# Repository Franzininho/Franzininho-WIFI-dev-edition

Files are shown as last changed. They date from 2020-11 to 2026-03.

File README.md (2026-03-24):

# Franzininho WiFi Developer Edition

The **Franzininho WiFi Developer Edition** is a development board designed to evaluate **ESP32-S2 modules** (WROOM and WROVER) and to support the development of the next generation of Franzininho boards.

The Franzininho project was created to help people develop skills in electronics and programming through *DIY* (Do-It-Yourself) activities, aligned with the *maker culture* in Brazil.

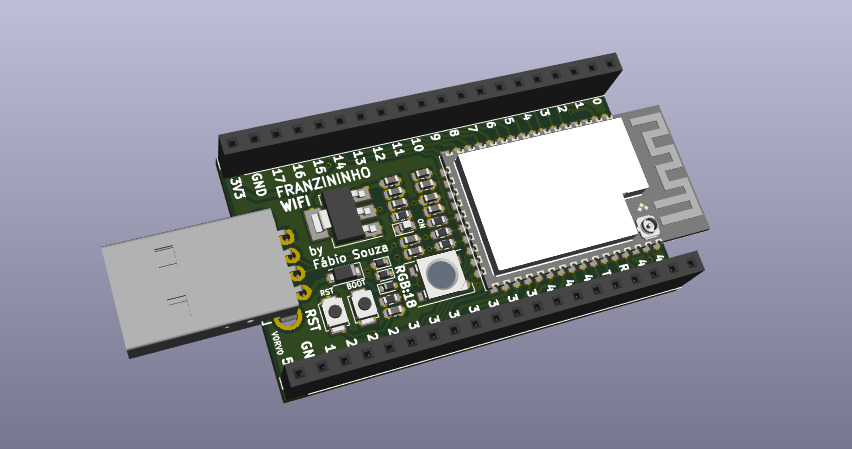
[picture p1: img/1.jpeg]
front


As there are still few ESP32-S2-based boards available in the Brazilian market, the Franzininho WiFi was developed to serve as a development platform for this SoC, as well as to help evaluate and validate applications.

---

## Features

### ESP32-S2 Module (WROOM or WROVER)
- Xtensa® LX7 32-bit single-core microprocessor, up to 240 MHz  
- 128 KB ROM  
- 320 KB SRAM  
- 16 KB RTC SRAM  
- 2 MB (8 Mbit) PSRAM (WROVER module only)  
- Wi-Fi 802.11 b/g/n  

### Interfaces
- GPIO, SPI, LCD, UART, I2C, I2S  
- Camera interface  
- IR, pulse counter, LED PWM  
- TWAI (compatible with ISO 11898-1)  
- USB 1.1 OTG  
- ADC, DAC  
- Touch sensor  
- Temperature sensor  

### Hardware
- USB Type-A male connector  
- RGB LED (WS2812) (GPIO 18)  
- 40 pins broken out to 2x20 headers (2.54 mm pitch, 36 GPIOs) — breadboard-friendly  
- Reset and DFU (BOOT0) buttons to enter the ROM bootloader (USB serial, no external adapter required)  
- Serial debug pins (TX and RX) for hardware debug console  
- JTAG pads for advanced debugging access  
- 3.3 V power indicator LED  
- 3.3 V voltage regulator  

### Power Supply
- Micro USB port (default power source)  
- 5 V and GND header pins  
- 3V3 and GND header pins  

### Dimensions
- 72 mm x 30 mm  

### Compatibility
- Compatible with [ESP-IDF](https://docs.espressif.com/projects/esp-idf/en/latest/esp32s2/get-started/index.html)  
- Compatible with [CircuitPython](https://circuitpython.org/)  

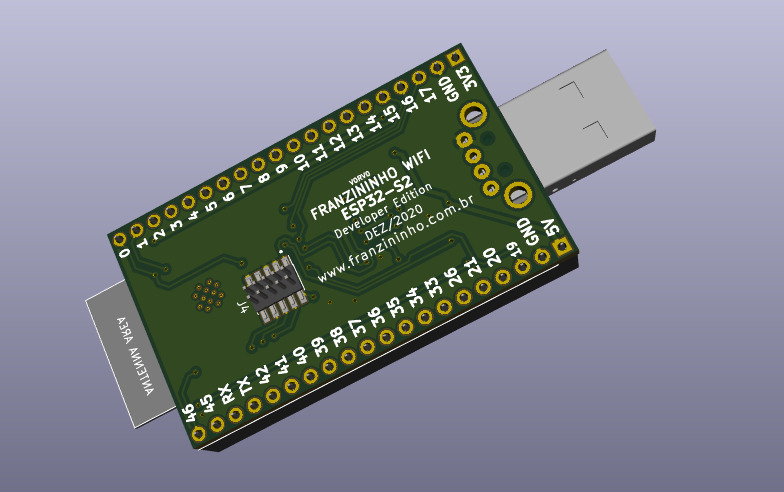
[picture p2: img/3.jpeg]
back


---

## License

This project is open-source hardware and is released under the **CERN Open Hardware License**.

The Franzininho WiFi board is certified by OSHWA:  
[UID BR000006](https://certification.oshwa.org/br000006.html)

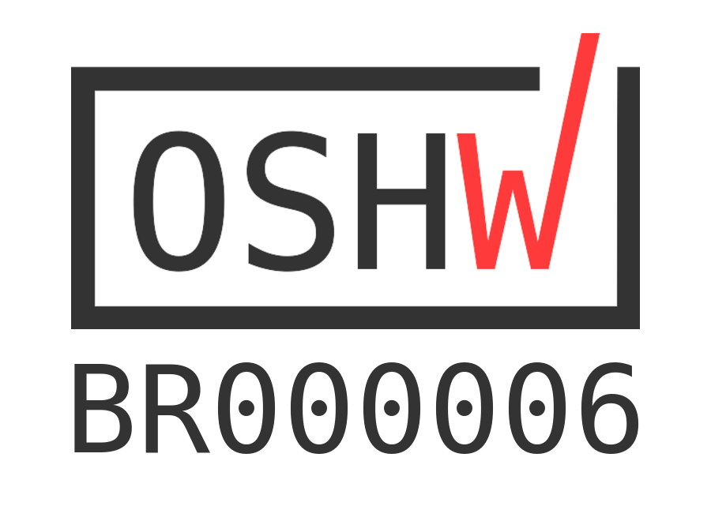
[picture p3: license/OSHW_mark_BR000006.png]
oshwa


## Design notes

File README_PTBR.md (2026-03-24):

# Franzininho WiFi

A **Franzininho WiFi** é uma placa de desenvolvimento projetada para avaliar os módulos **ESP32-S2** (WROOM e WROVER) e apoiar a criação da nova geração de placas Franzininho.

O projeto Franzininho foi criado com o objetivo de desenvolver habilidades em eletrônica e programação, por meio de atividades no formato *DIY* (faça você mesmo) e alinhadas à cultura *maker*, no Brasil.

front

Como ainda há poucas placas com ESP32-S2 disponíveis no mercado brasileiro, a Franzininho WiFi foi desenvolvida para servir como uma plataforma de desenvolvimento baseada nesse SoC, além de auxiliar na avaliação e validação de aplicações.

---

## Características

### Módulo ESP32-S2 (WROOM ou WROVER)
- Microprocessador Xtensa® LX7, 32 bits, single-core, até 240 MHz  
- 128 KB de ROM  
- 320 KB de SRAM  
- 16 KB de SRAM em RTC  
- 2 MB (8 Mbit) de PSRAM (apenas no módulo WROVER)  
- Wi-Fi 802.11 b/g/n  

### Interfaces
- GPIO, SPI, LCD, UART, I2C, I2S  
- Interface para câmera  
- IR, contador de pulsos, PWM para LED  
- TWAI (compatível com ISO 11898-1)  
- USB 1.1 OTG  
- ADC, DAC  
- Sensor de toque  
- Sensor de temperatura  

### Hardware
- Conector USB Tipo-A macho  
- LED RGB (WS2812) (GPIO 18)  
- 40 pinos expostos em headers 2x20 (passo 2,54 mm, 36 GPIOs) — compatível com protoboard  
- Botões de Reset e DFU (BOOT0) para acesso ao bootloader ROM (via USB, sem necessidade de cabo adicional)  
- Pinos de depuração serial (TX e RX)  
- Pads JTAG para depuração avançada  
- LED indicador de alimentação 3,3 V  
- Regulador de 3,3 V  

### Alimentação
- Porta Micro USB (padrão)  
- Pinos 5 V e GND  
- Pinos 3V3 e GND  

### Dimensões
- 72 mm x 30 mm  

### Compatibilidade
- Compatível com [ESP-IDF](https://docs.espressif.com/projects/esp-idf/en/latest/esp32s2/get-started/index.html)  
- Compatível com [CircuitPython](https://circuitpython.org/)  

back

---

## Licença

Este projeto é um hardware de código aberto e está disponível sob a licença **CERN Open Hardware License**.

A placa Franzininho WiFi é certificada pela OSHWA:  
[UID BR000006](https://certification.oshwa.org/br000006.html)

oshwa

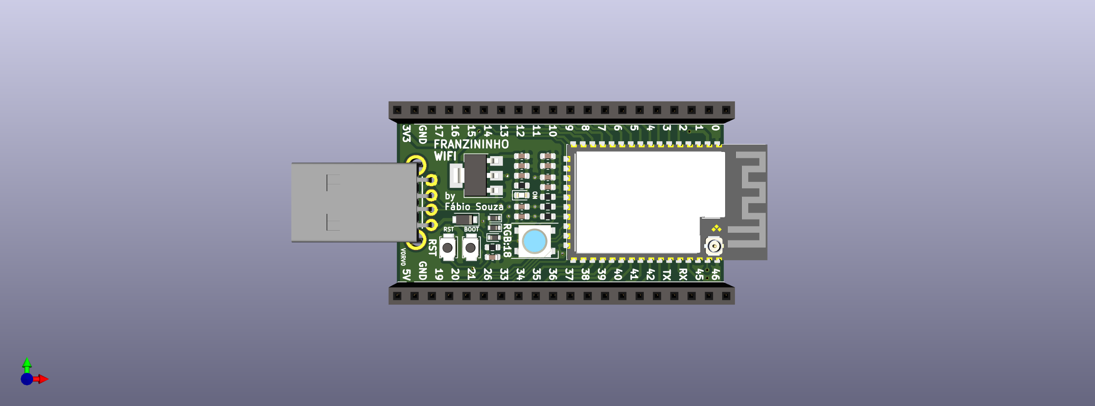
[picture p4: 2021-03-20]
img/Franzininho WIFI.png

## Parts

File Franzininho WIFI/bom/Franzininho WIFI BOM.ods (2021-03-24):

Reference | Value | Footprint | Datasheet | LCSC | PN | Montado | Tem estoque
C4 | 20pF | Capacitor_SMD:C_0603_1608Metric | https://datasheet.lcsc.com/szlcsc/Samsung-Electro-Mechanics-CL10C200JB8NNNC_C1648.pdf | C1648 | CL10C200JB8NNNC | Sim | Não
J2 | Conn_01x20_Male | Connector_PinSocket_2.54mm:PinSocket_1x20_P2.54mm_Vertical | ~ |  |  | Sim | Não
R3 | 0 | Resistor_SMD:R_0603_1608Metric | ~ | C21189 | 0603WAF0000T5E | Sim | Não
R4 | 0 | Resistor_SMD:R_0603_1608Metric | ~ | C21189 | 0603WAF0000T5E | Sim | Não
C3 | 10uF | Capacitor_SMD:C_0603_1608Metric | Samsung-Electro-Mechanics-CL10A106KP8NNNC_C19702.pdf | C19702 | CL10A106KP8NNNC | Sim | Não
C1 | 10uF | Capacitor_SMD:C_0603_1608Metric | Samsung-Electro-Mechanics-CL10A106KP8NNNC_C19702.pdf | C19702 | CL10A106KP8NNNC | Sim | Não
C7 | 10uF | Capacitor_SMD:C_0603_1608Metric | Samsung-Electro-Mechanics-CL10A106KP8NNNC_C19702.pdf | C19702 | CL10A106KP8NNNC | Sim | Não
C9 | 10uF | Capacitor_SMD:C_0603_1608Metric | Samsung-Electro-Mechanics-CL10A106KP8NNNC_C19702.pdf | C19702 | CL10A106KP8NNNC | Sim | Não
D3 | 1N5819W | Diode_SMD:D_SOD-123F | Shandong-Jingdao-Microelectronics-1N5819W_C169540.pdf | C169540 | 1N5819W | Sim | Não
C6 | 1uF | Capacitor_SMD:C_0603_1608Metric | https://datasheet.lcsc.com/szlcsc/Samsung-Electro-Mechanics-CL10A105KB8NNNC_C15849.pdf | C15849 | CL10A105KB8NNNC | Sim | Não
C5 | 20pF | Capacitor_SMD:C_0603_1608Metric | https://datasheet.lcsc.com/szlcsc/Samsung-Electro-Mechanics-CL10C200JB8NNNC_C1648.pdf | C1648 | CL10C200JB8NNNC | Sim | Não
U2 | BL1117-33CX | Package_TO_SOT_SMD:SOT-223-3_TabPin2 | https://datasheet.lcsc.com/szlcsc/Shanghai-Belling-BL1117-33CX_C5400.pdf | C5400 | BL1117-33CX | Sim | Não
J3 | Conn_01x20_Male | Connector_PinSocket_2.54mm:PinSocket_1x20_P2.54mm_Vertical | ~ |  |  | Sim | Não
D1 | LESD5D5.0CT1G | Diode_SMD:D_SOD-523 | https://datasheet.lcsc.com/szlcsc/Leshan-Radio-LESD5Z5-0T1G_C136171.pdf | C136171 | LESD5Z5.0T1G | Sim | Não
D2 | LESD5D5.0CT1G | Diode_SMD:D_SOD-523 | https://datasheet.lcsc.com/szlcsc/Leshan-Radio-LESD5Z5-0T1G_C136171.pdf | C136171 | LESD5Z5.0T1G | Sim | Não
D4 | LESD5D5.0CT1G | Diode_SMD:D_SOD-523 | https://datasheet.lcsc.com/szlcsc/Leshan-Radio-LESD5Z5-0T1G_C136171.pdf | C136171 | LESD5Z5.0T1G | Sim | Não
J1 | USB-A-H | LIBS:USB-A-H |  | C112454 | USB-05 | Sim | Não
D6 | WS2812B | LED_SMD:LED_WS2812B_PLCC4_5.0x5.0mm_P3.2mm | https://datasheet.lcsc.com/szlcsc/Worldsemi-WS2812B-B_C114586.pdf | C114586 | WS2812B-B | Sim | Não
C2 | 100nF | Capacitor_SMD:C_0603_1608Metric | https://datasheet.lcsc.com/szlcsc/YAGEO-CC0603KRX7R9BB104_C14663.pdf | C14663 | CC0603KRX7R9BB104 | Sim | Sim
C8 | 100nF | Capacitor_SMD:C_0603_1608Metric | https://datasheet.lcsc.com/szlcsc/YAGEO-CC0603KRX7R9BB104_C14663.pdf | C14663 | CC0603KRX7R9BB104 | Sim | Sim
C10 | 100nF | Capacitor_SMD:C_0603_1608Metric | https://datasheet.lcsc.com/szlcsc/YAGEO-CC0603KRX7R9BB104_C14663.pdf | C14663 | CC0603KRX7R9BB104 | Sim | Sim
R1 | 10k | Resistor_SMD:R_0603_1608Metric | ~ | C25804 | 0603WAF1002T5E | Sim | Sim
R2 | 10k | Resistor_SMD:R_0603_1608Metric | ~ | C25804 | 0603WAF1002T5E | Sim | Sim
R5 | 10k | Resistor_SMD:R_0603_1608Metric | ~ | C25804 | 0603WAF1002T5E | Sim | Sim
U1 | esp32-s2-wroom | esp32-s2:esp32-s2-wrooom | https://www.espressif.com/sites/default/files/documentation/esp32-s2-wroom_esp32-s2-wroom-i_datasheet_en.pdf | C967025 | ESP32-S2-WROOM(4M) | Sim | Sim
D5 | LED | LED_SMD:LED_0603_1608Metric | https://datasheet.lcsc.com/szlcsc/Hubei-KENTO-Elec-XL-0603QYGC_C2289.pdf | C2289 | XL-0603QYGC | Sim | Sim
SW1 | SW_Push | Button_Switch_SMD:SW_SPST_B3U-1000P | https://datasheet.lcsc.com/szlcsc/1810010153_Omron-Electronics-B3U-1000P_C231329.pdf | C231329 | B3U-1000P | Sim | Sim
SW2 | SW_Push | Button_Switch_SMD:SW_SPST_B3U-1000P | https://datasheet.lcsc.com/szlcsc/1810010153_Omron-Electronics-B3U-1000P_C231329.pdf | C231329 | B3U-1000P | Sim | Sim

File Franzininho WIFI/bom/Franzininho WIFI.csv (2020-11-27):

Id | Designator | Package | Quantity | Designation | Supplier and ref
1 | G*** | bandeiraBrasil | 1 | LOGO
2 | G*** | logo-franzininho12_7 | 1 | LOGO
3 | J3,J2 | PinSocket_1x20_P2.54mm_Vertical | 2 | Conn_01x20_Male
4 | C2,C8,C10 | C_0603_1608Metric | 3 | 100nF
5 | R1,R2,R5 | R_0603_1608Metric | 3 | 10k
6 | U1 | esp32-s2-wrooom | 1 | esp32-s2-wroom
7 | C1,C3,C7,C9 | C_0603_1608Metric | 4 | 10uF
8 | C4,C5 | C_0603_1608Metric | 2 | 20pF
9 | C6 | C_0603_1608Metric | 1 | 1uF
10 | D3 | D_SOD-123F | 1 | 1N5819W
11 | J1 | USB-A-H | 1 | USB-A-H
12 | R3,R4 | R_0603_1608Metric | 2 | 0
13 | D1,D2,D4 | D_SOD-523 | 3 | LESD5D5.0CT1G
14 | U2 | SOT-223-3_TabPin2 | 1 | BL1117-33CX
15 | D5 | LED_0603_1608Metric | 1 | LED
16 | SW1,SW2 | SW_SPST_B3U-1000P | 2 | SW_Push
17 | D6 | LED_WS2812B_PLCC4_5.0x5.0mm_P3.2mm | 1 | WS2812B
18 | J4 | PinHeader_2x05_P1.27mm_Vertical_SMD | 1 | Conn_ARM_JTAG_SWD_10

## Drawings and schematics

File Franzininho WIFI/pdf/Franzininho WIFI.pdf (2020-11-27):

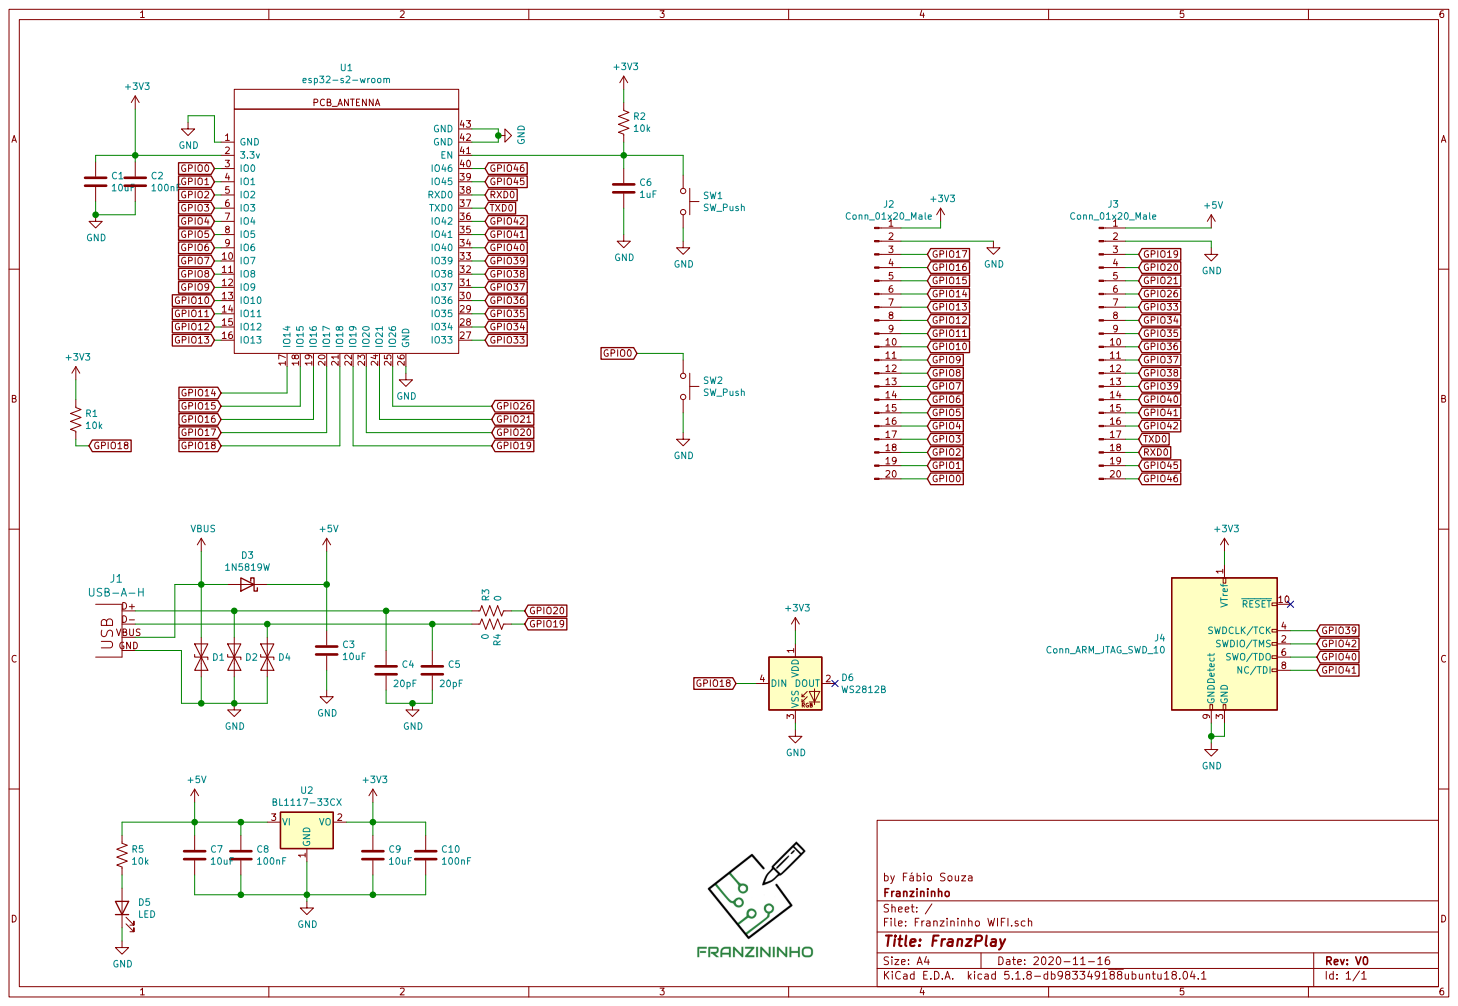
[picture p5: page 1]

3 SWDCLK/TCK 4 SWO/TDO 6 NC/TDI 8 GNDDetect 9

File: Franzininho WIFI.sch Sheet: / Franzininho

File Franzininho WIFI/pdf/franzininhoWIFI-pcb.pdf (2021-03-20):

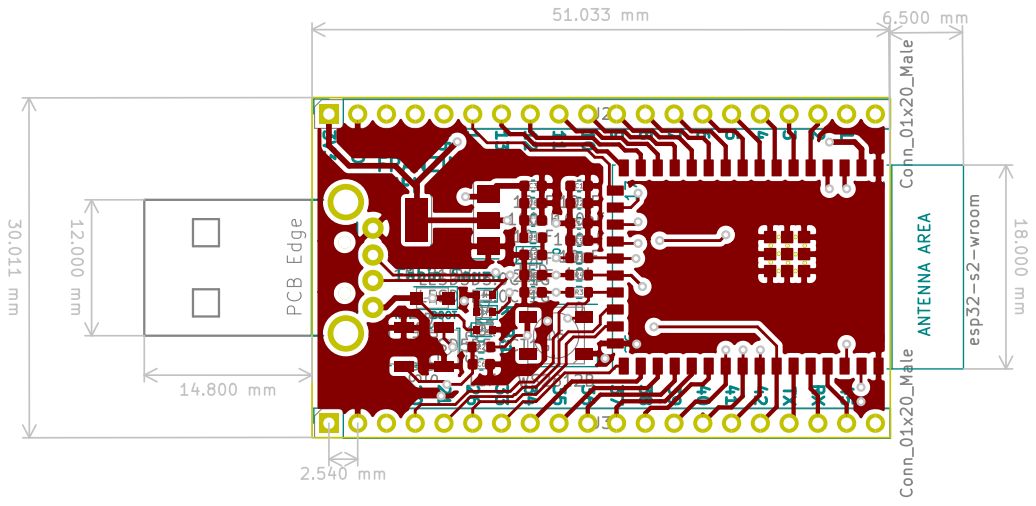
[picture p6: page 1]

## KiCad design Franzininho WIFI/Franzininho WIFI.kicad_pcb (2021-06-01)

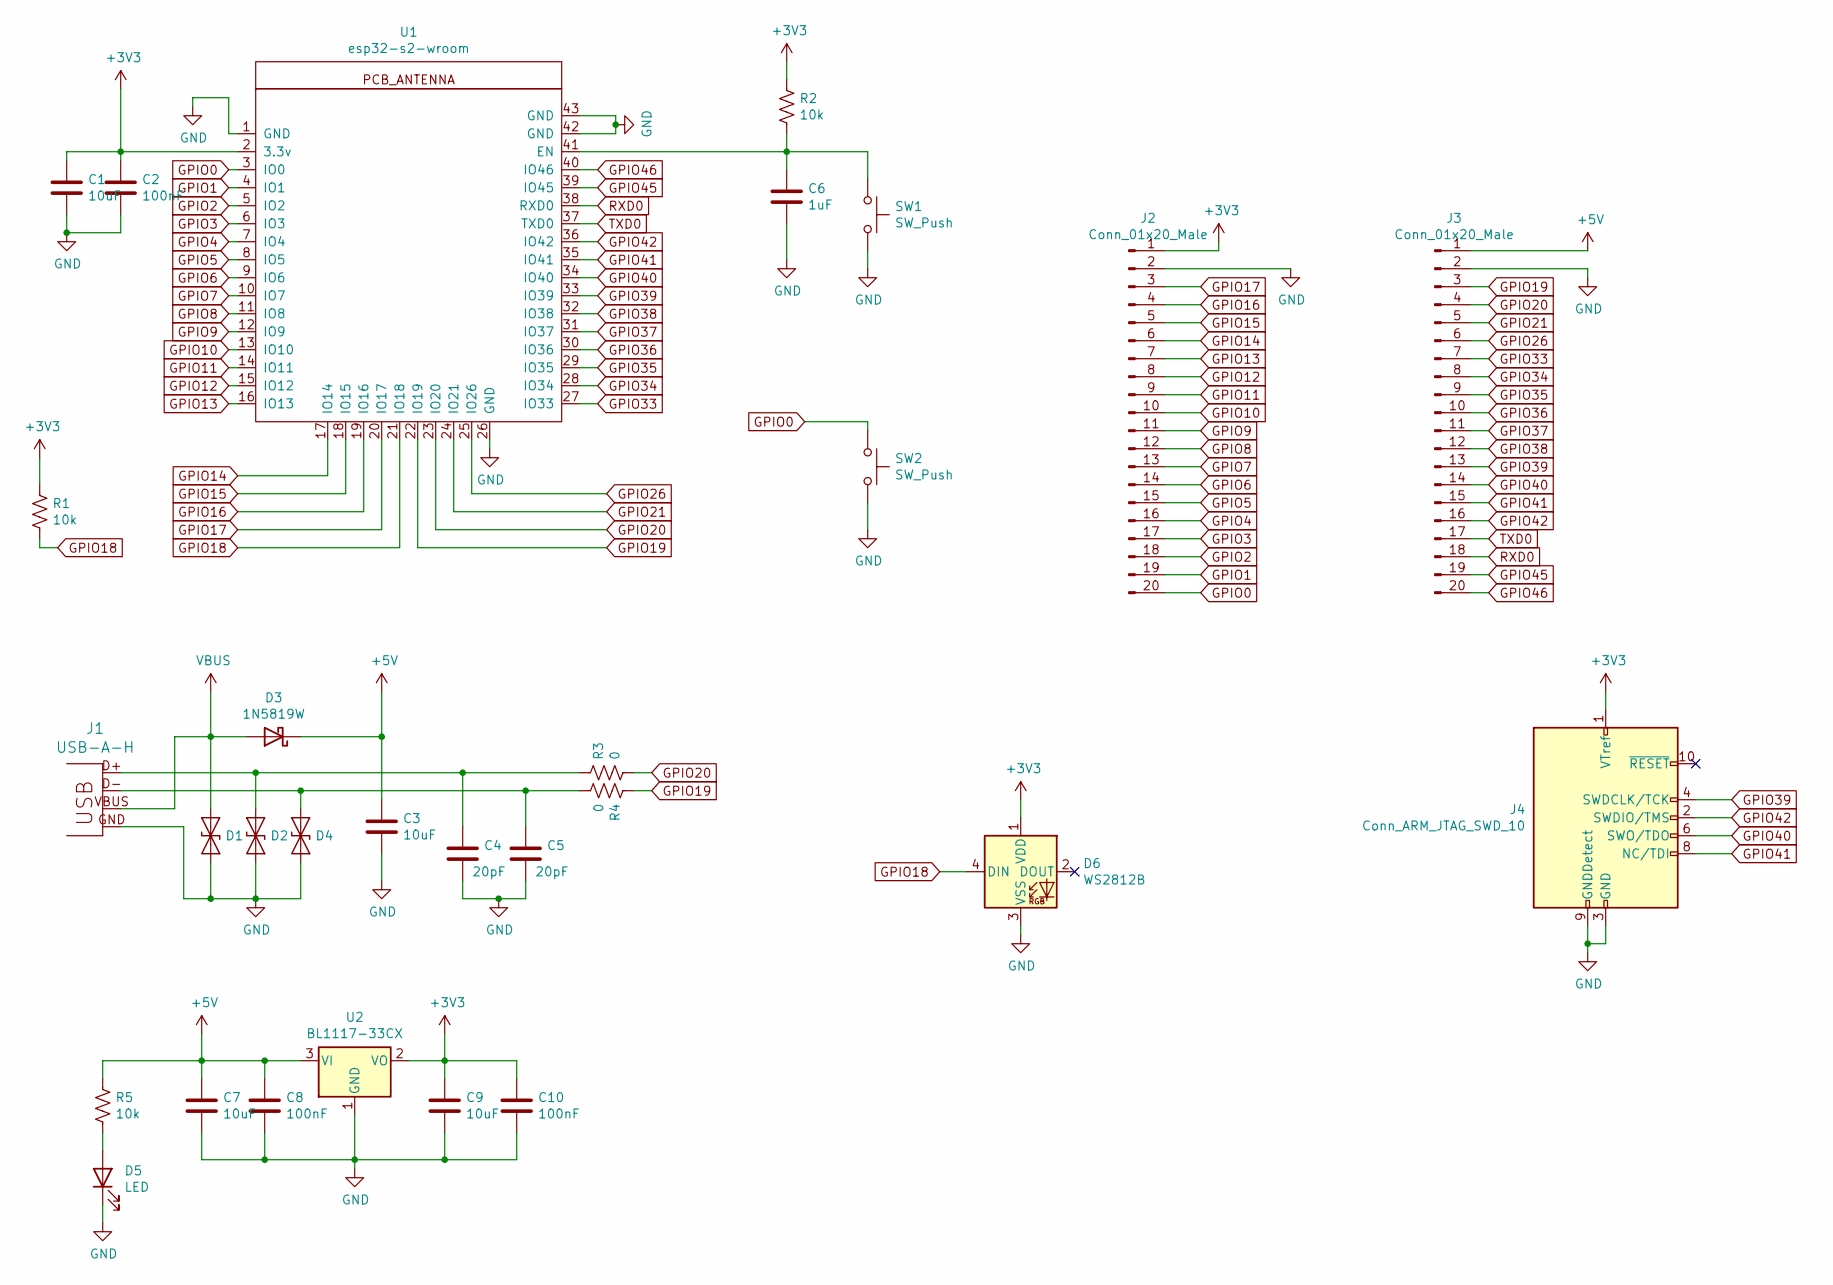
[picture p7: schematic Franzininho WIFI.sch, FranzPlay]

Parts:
C1, C3, C7, C9: 10uF; C_0603_1608Metric; LCSC C19702
C2, C8, C10: 100nF; C_0603_1608Metric; LCSC C14663
C4, C5: 20pF; C_0603_1608Metric; LCSC C1648
C6: 1uF; C_0603_1608Metric; LCSC C15849
D1, D2, D4: LESD5D5.0CT1G; D_SOD-523; LCSC C136171
D3: 1N5819W; D_SOD-123F; LCSC C169540
D5: LED; LED_0603_1608Metric; LCSC C2289
D6: WS2812B; LED_WS2812B_PLCC4_5.0x5.0mm_P3.2mm; LCSC C114586
J1: USB-A-H
J2, J3: Conn_01x20_Male; PinSocket_1x20_P2.54mm_Vertical
J4: Conn_ARM_JTAG_SWD_10; PinHeader_2x05_P1.27mm_Vertical_SMD
R1, R2, R5: 10k; R_0603_1608Metric; LCSC C25804
R3, R4: 0; R_0603_1608Metric; LCSC C21189
SW1, SW2: SW_Push; SW_SPST_B3U-1000P
U1: esp32-s2-wroom; esp32-s2-wrooom
U2: BL1117-33CX; SOT-223-3_TabPin2; LCSC C5400

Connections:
+3V3: C1.1, C2.1, C9.1, C10.1, D6.1 (VDD), J2.1, J4.1 (VTref), R1.1, R2.1, U1.2 (3.3v), U2.2 (VO)
+5V: C3.1, C7.1, C8.1, D3.1 (K), J3.1, R5.1, U2.3 (VI)
GND: C1.2, C2.2, C3.2, C4.2, C5.2, C6.2, C7.2, C8.2, C9.2, C10.2, D1.2 (A2), D2.2 (A2), D4.2 (A2), D5.1 (K), D6.3 (VSS), J1.GND, J2.2, J3.2, J4.3 (GND), J4.5 (GND), J4.9 (GNDDetect), SW1.2, SW2.2, U1.1 (GND), U1.26 (GND), U1.42 (GND), U1.43 (GND), U2.1 (GND)
GPIO0: J2.20, SW2.1, U1.3 (IO0)
GPIO1: J2.19, U1.4 (IO1)
GPIO2: J2.18, U1.5 (IO2)
GPIO3: J2.17, U1.6 (IO3)
GPIO4: J2.16, U1.7 (IO4)
GPIO5: J2.15, U1.8 (IO5)
GPIO6: J2.14, U1.9 (IO6)
GPIO7: J2.13, U1.10 (IO7)
GPIO8: J2.12, U1.11 (IO8)
GPIO9: J2.11, U1.12 (IO9)
GPIO10: J2.10, U1.13 (IO10)
GPIO11: J2.9, U1.14 (IO11)
GPIO12: J2.8, U1.15 (IO12)
GPIO13: J2.7, U1.16 (IO13)
GPIO14: J2.6, U1.17 (IO14)
GPIO15: J2.5, U1.18 (IO15)
GPIO16: J2.4, U1.19 (IO16)
GPIO17: J2.3, U1.20 (IO17)
GPIO18: D6.4 (DIN), R1.2, U1.21 (IO18)
GPIO19: J3.3, R4.1, U1.22 (IO19)
GPIO20: J3.4, R3.2, U1.23 (IO20)
GPIO21: J3.5, U1.24 (IO21)
GPIO26: J3.6, U1.25 (IO26)
GPIO33: J3.7, U1.27 (IO33)
GPIO34: J3.8, U1.28 (IO34)
GPIO35: J3.9, U1.29 (IO35)
GPIO36: J3.10, U1.30 (IO36)
GPIO37: J3.11, U1.31 (IO37)
GPIO38: J3.12, U1.32 (IO38)
GPIO39: J3.13, J4.4 (SWDCLK/TCK), U1.33 (IO39)
GPIO40: J3.14, J4.6 (SWO/TDO), U1.34 (IO40)
GPIO41: J3.15, J4.8 (NC/TDI), U1.35 (IO41)
GPIO42: J3.16, J4.2 (SWDIO/TMS), U1.36 (IO42)
GPIO45: J3.19, U1.39 (IO45)
GPIO46: J3.20, U1.40 (IO46)
unnamed: C4.1, D2.1 (A1), J1.D+, R3.1
unnamed: C5.1, D4.1 (A1), J1.D-, R4.2
unnamed: C6.1, R2.2, SW1.1, U1.41 (EN)
unnamed: D5.2 (A), R5.2
RXD0: J3.18, U1.38 (RXD0)
TXD0: J3.17, U1.37 (TXD0)
VBUS: D1.1 (A1), D3.2 (A), J1.VBUS

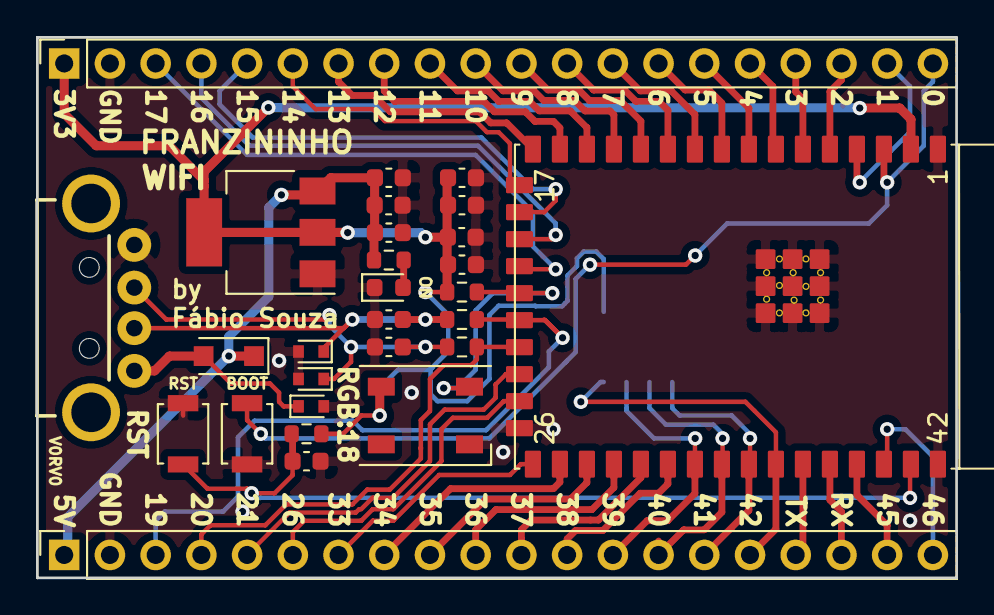
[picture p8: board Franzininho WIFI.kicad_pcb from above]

Board: 2 copper layers, 51.1 x 30.0 mm, 29 parts (0 on the bottom side), 45 nets.

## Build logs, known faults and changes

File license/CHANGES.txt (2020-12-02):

Here we are compiling a community changelog.

If you come up with a modification of our designs, please share it with the community, log your changes below, and upload the files to our GitHub repository.

Change Format
Your name Date Description of modification

Change Log

Fabio Souza 2020-11-26 Initial release of Franzininho WIFI under CERN OHL v1.2 or later.

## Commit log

2020-12-22 Adicionando InteractiveHtmlBom para visualização dos componentes na montagem
2021-03-20 Adicionando iamgens e organizando as pastas
    [Franzininho WIFI BOM.csv, Franzininho WIFI BOM.ods, Franzininho WIFI.csv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]
2021-03-24 Ajustando plnailha BOM
    [Franzininho WIFI BOM.ods]
2021-04-22 Ajuste de tradução de License para Licença
2021-06-01 Adicionando arquivo de posicionamento dos componentes
    [Franzininho WIFI.kicad_pcb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]
2022-04-12 Atualizando o nome para developer edition
